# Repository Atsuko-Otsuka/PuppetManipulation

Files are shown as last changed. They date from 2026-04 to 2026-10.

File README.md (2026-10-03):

# VRぬいぐるみアバター操作システム

ぬいぐるみの身体動作を用いてVR空間のアバターを操作するシステムです。ユーザーがぬいぐるみを「触る」「動かす」ことで、アバターに直感的な身体表現を与えます。全身ボディトラッキングのような装着負担を抑えながら、手軽に自然な操作を実現することを目指しています。

## 概要

### 背景

VR空間におけるアバター操作は普及が進む一方で、従来の手法には次のような課題がありました。

- 全身ボディトラッキングでは、ユーザー自身の身体動作をそのまま反映できる一方で、装着や長時間の運用に伴う身体的負担が大きい
- ボタン式コントローラでは、比較的手軽に操作できる一方で、入力とアバターの動作が一致せず、身体としての直感的な操作が難しい

### 提案

本システムでは、これらの課題を同時に解決するために「ぬいぐるみ」をインターフェースとして採用しました。

ぬいぐるみを用いることで、ユーザーは自然な身体動作をそのままアバター操作に転写できます。これにより、最小限の身体負荷で思い通りの動作を実現しつつ、ユーザーの心理的ハードルを下げることができます。特に、ぬいぐるみを媒介にすることで、キャラクターになりきって大胆で愛らしい動作を自然に引き出すことが可能になります。

## システム構成
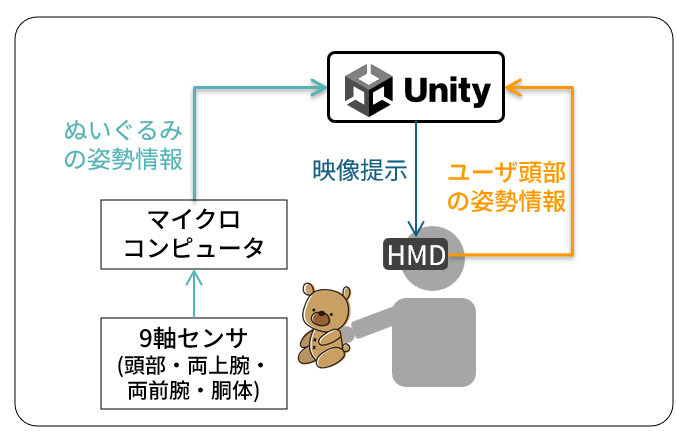
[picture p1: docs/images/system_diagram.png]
フロー図


### 主要な構成

- 9軸センサ（頭部、両上腕、両前腕、胴体）
- マルチプレクサ（I2C通信）
- XIAO ESP32-C6 マイコン
- Unity ベースのVRアプリケーション
- Meta Quest 3 による視覚提示
- 3Dプリントした筐体とぬいぐるみ内部への搭載

### 通信構成

```
9軸センサ × 7
   ↓ I2C
マルチプレクサ
   ↓ I2C
XIAO ESP32-C6 (マイコン)
   ↓ UDP
PC (Unity)
   ↓
Meta Quest 3 HMD
```

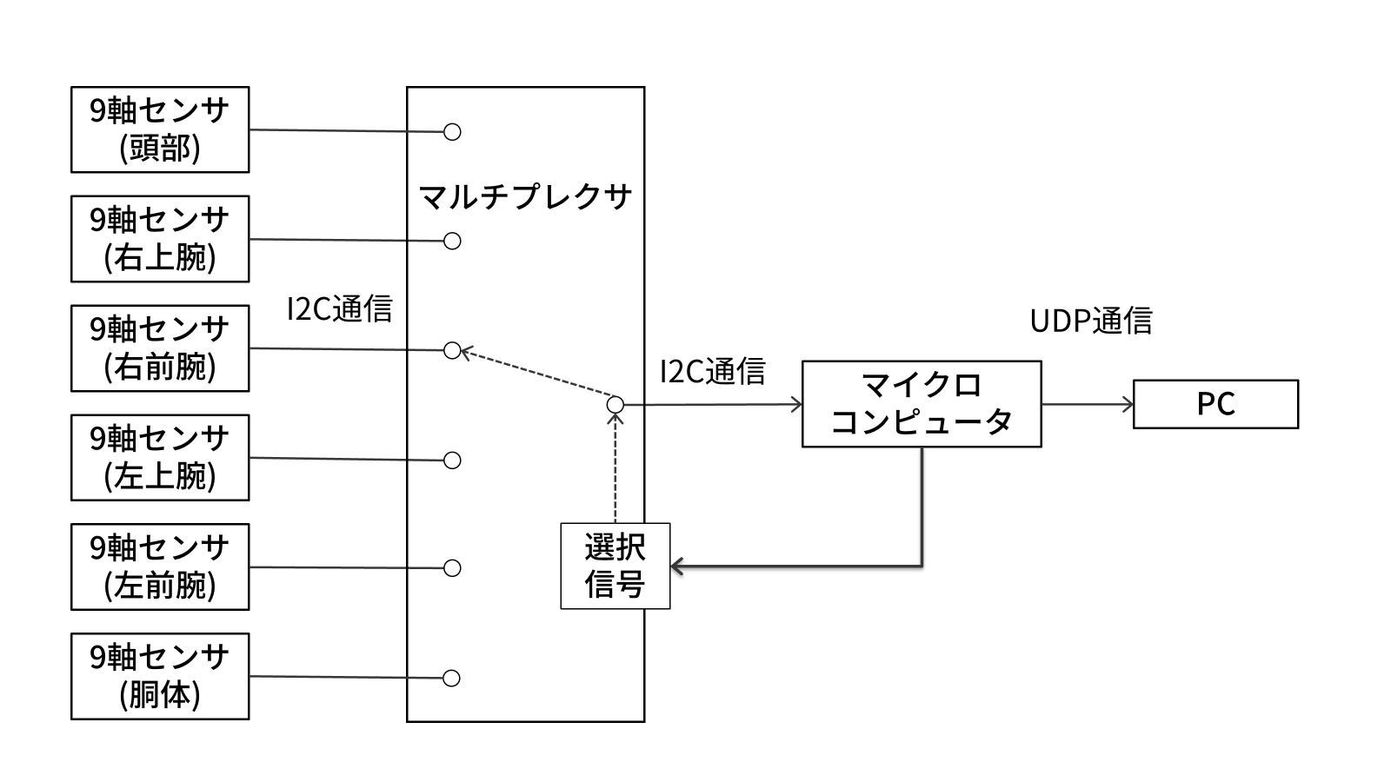
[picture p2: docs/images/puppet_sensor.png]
ハードウェア構成


- センサ群は I2C で集約されます
- マイコンがセンサデータを PC に送信します
- PC 上の Unity でアバターの姿勢と動作を更新します
- HMD によってユーザーは VR 空間でアバターを視覚的に確認します

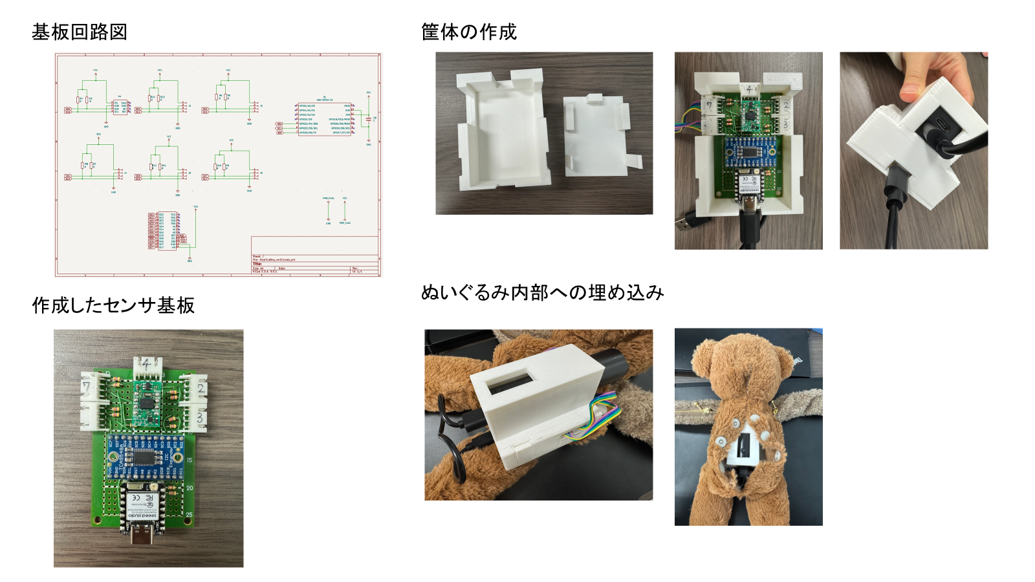
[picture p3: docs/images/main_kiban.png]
メイン基板

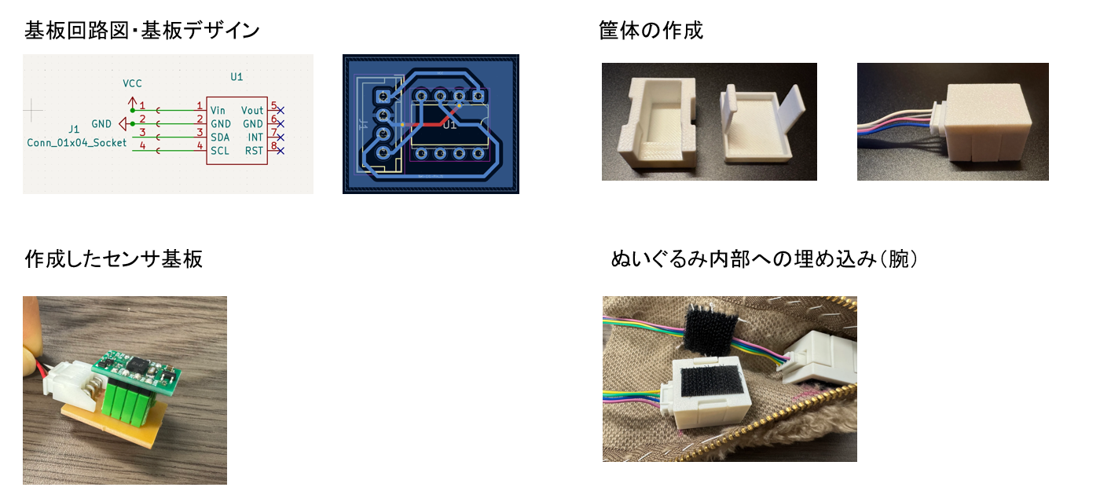
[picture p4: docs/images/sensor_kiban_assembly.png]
センサ基板


## 使用技術

- Unity（VRアプリケーション開発、アバター制御）
- Arduino IDE / XIAO ESP32-C6（センサデータの取得、PCへのデータ送信）
- KiCad（基板作成）
- Meta Quest 3（ユーザーへの視覚提示）
- Fusion360 / Bamboo Studio（筐体のモデリング、3Dプリンター印刷）

## 通信方式

本システムでは、センサデータを PC へ送信するために UDP 通信を採用しています。

- 通信方式: UDP
- 通信対象: マイコンボード → PC
- 役割: 9軸センサの姿勢情報をリアルタイムに送信し、Unityでアバター制御に反映
- 特徴: 低遅延・ワイヤレス・リアルタイム操作に適している

センサデータはI2Cでマルチプレクサ経由で収集され、ESP32-C6側でパケット化されたのち、Unityへ送信されます。

## ハードウェア詳細

### センサ配置

本システムでは7箇所に9軸センサを配置しています。

- 頭部
- 右上腕
- 右前腕
- 左上腕
- 左前腕
- 胴体
- 追加の計測部位（実装に応じて可変）

### 基板と筐体

- KiCad で設計したセンサ基板を使用
- マルチプレクサにより複数のセンサを一括制御
- 3Dプリントで筐体を作成し、ぬいぐるみの内部へ埋め込み
- ぬいぐるみの内部にセンサユニットを埋め込み、見た目と操作性を両立

### 3Dプリントと製作例

- 基板回路図と基板デザインを作成
- 筐体をプリントして内部に組み込み
- ぬいぐるみ内部へセンサー基板と配線を納めて完成

## システムの流れ

1. ぬいぐるみの各部位で姿勢が変化する
2. 9軸センサがその変化を計測する
3. マルチプレクサを介してマイコンへ送信される
4. XIAO ESP32-C6 が UDP で Unity 側へデータ送信する
5. Unity が受信した姿勢情報をアバターの各部位へ適用する
6. HMD を通じてユーザーは VR 空間で操作結果を確認する

## 実装上のポイント

- センサの取り付け位置は、アバターの自然な動きと操作性を両立するように設計
- ぬいぐるみ内部への埋め込みにより、見た目の違和感を抑制
- アバターの動きは、姿勢角度をそのまま各ボーンへ反映するのではなく、必要に応じて補正や平滑化を行う
- UDP の低遅延性を活かして、VR環境における直感的な操作を優先

## 実装ファイル

このリポジトリには、Unity側の操作スクリプトやシリアル/UDP関連の実装が含まれています。

- Unity アプリケーション: `PuppetManipulation_Software/`
- ハードウェア(基板、Arduino IDE、3Dプリンタデータなど): `PuppetManipulation_Hardware/`
- センサ制御と通信: `Assets/` 配下のスクリプト群
- キャラクター制御: `Assets/Scripts/Puppet/` など

## セットアップ

### 必要な環境

- Unity
- Meta Quest 3
- XIAO ESP32-C6
- Arduino IDE
- KiCad（基板改造時）
- 3Dプリンタ（筐体作成時）

### 基本的な手順

1. このリポジトリをクローンする
2. Unity プロジェクトを開く
3. マイコンにセンサ制御プログラムを書き込む
4. ぬいぐるみにセンサユニットを取り付ける
5. Unity 実行時に UDP 接続を確認する
6. VR 空間でアバターが動くことを確認する

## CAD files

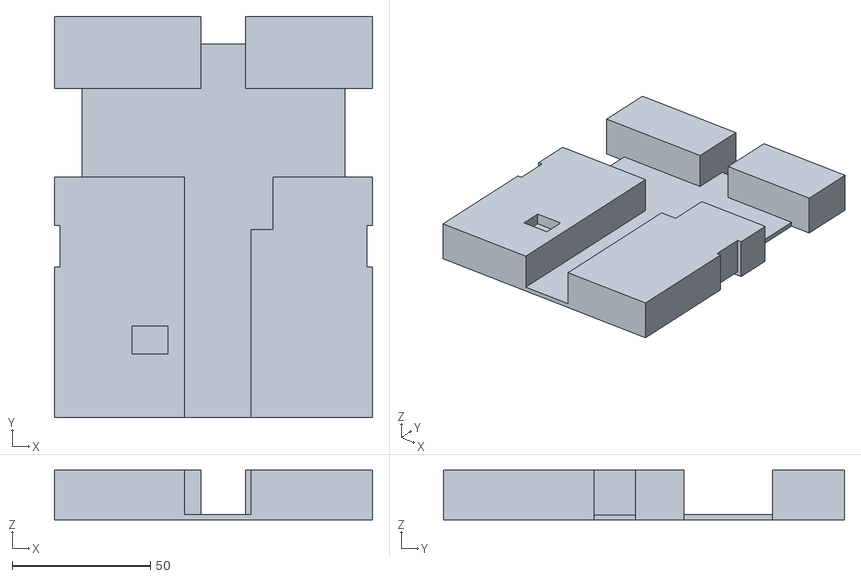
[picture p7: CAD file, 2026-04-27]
PuppetManipulation_Hardware/3DPrinter/mainPico_box.stl
115.0 x 145.0 x 18.0

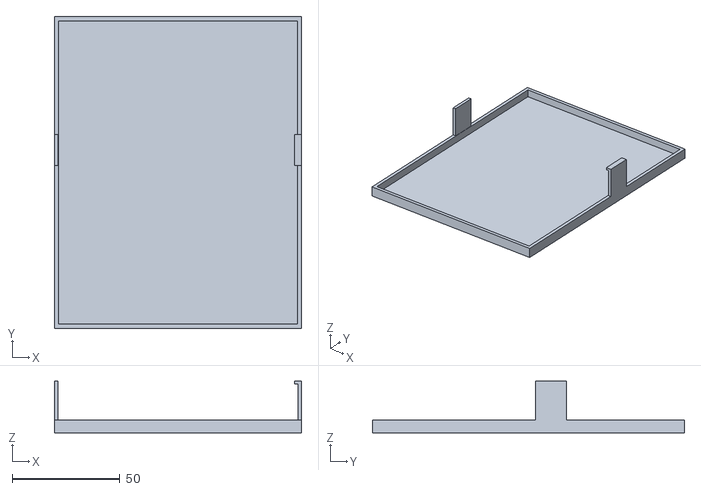
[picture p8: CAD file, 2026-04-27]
PuppetManipulation_Hardware/3DPrinter/mainPico_cover.stl
115.0 x 145.0 x 24.0

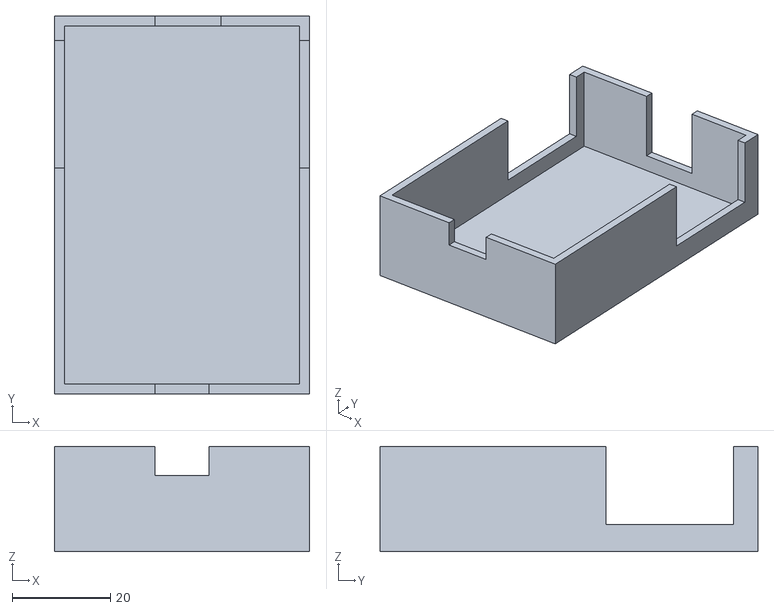
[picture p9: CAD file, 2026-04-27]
PuppetManipulation_Hardware/3DPrinter/XIAO+Multi+9jiku6_Box.stl
52.0 x 77.0 x 21.5

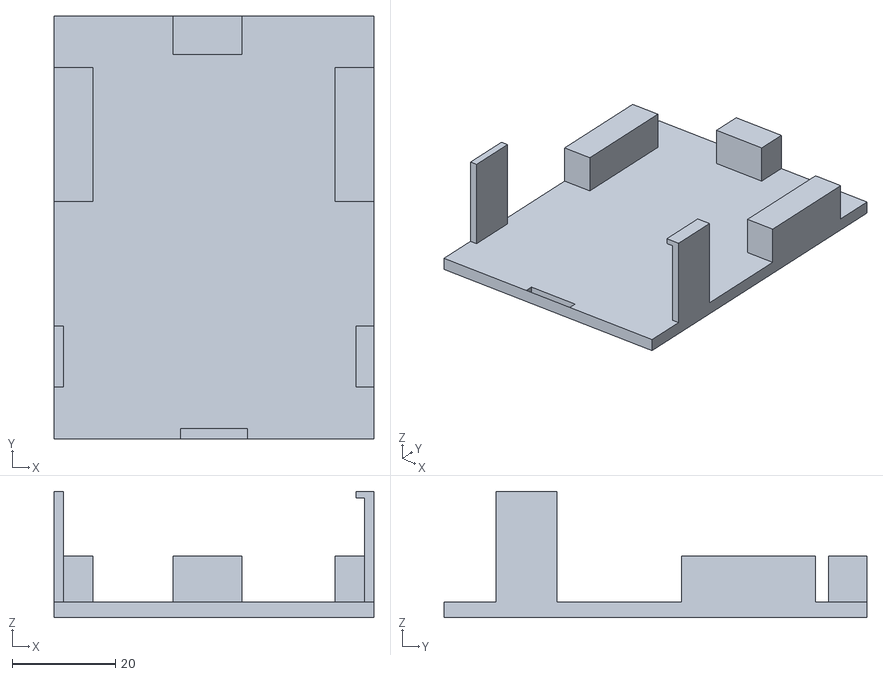
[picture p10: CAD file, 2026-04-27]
PuppetManipulation_Hardware/3DPrinter/XIAO+Multi+9jiku6_Cover_ver2.2.stl
62.0 x 82.0 x 24.5

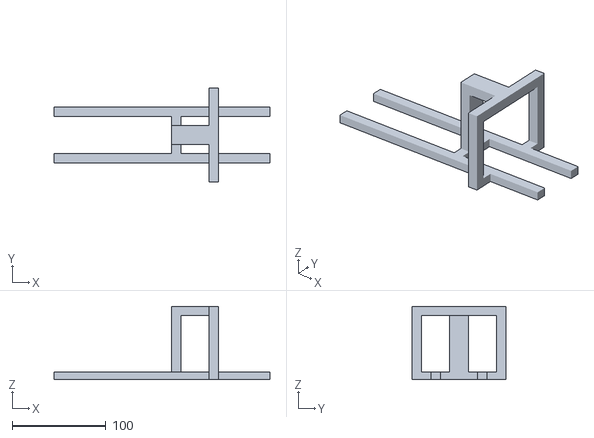
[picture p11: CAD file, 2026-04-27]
PuppetManipulation_Hardware/3DPrinter/PuppetStandStick_ver2.stl
230.0 x 100.0 x 78.1

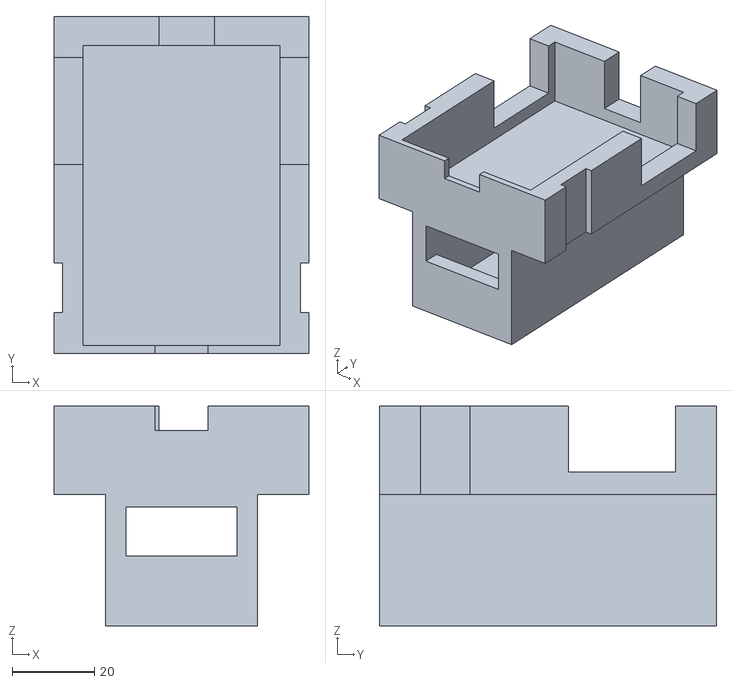
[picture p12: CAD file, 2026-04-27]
PuppetManipulation_Hardware/3DPrinter/XIAO+Multi+9jiku6_Battery_Box.stl
62.0 x 82.0 x 53.5

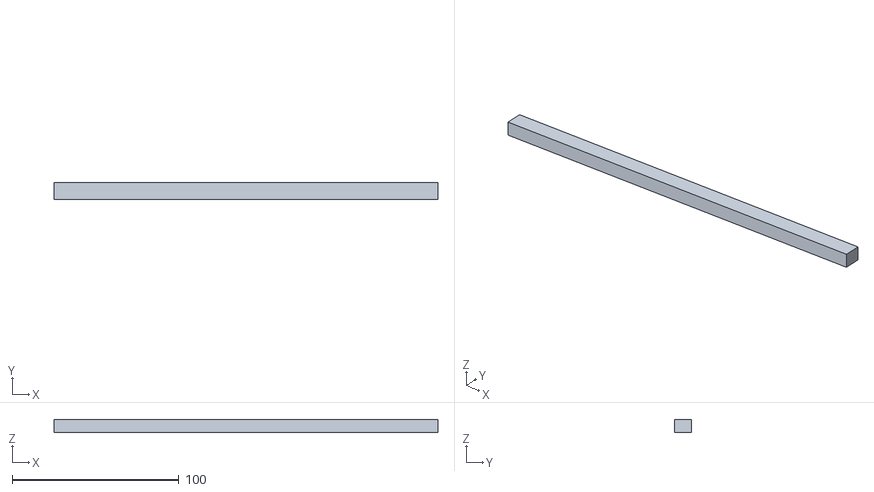
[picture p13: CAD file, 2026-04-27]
PuppetManipulation_Hardware/3DPrinter/PuppetStandStick.stl
230.0 x 10.1 x 8.05

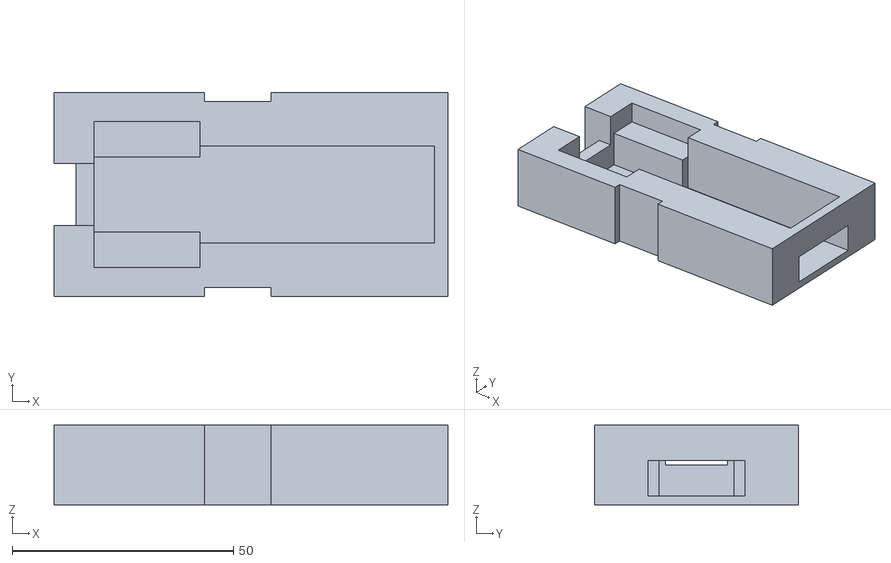
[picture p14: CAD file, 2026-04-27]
PuppetManipulation_Hardware/3DPrinter/RasPi_BNO2_Box.stl
89.0 x 46.0 x 18.0

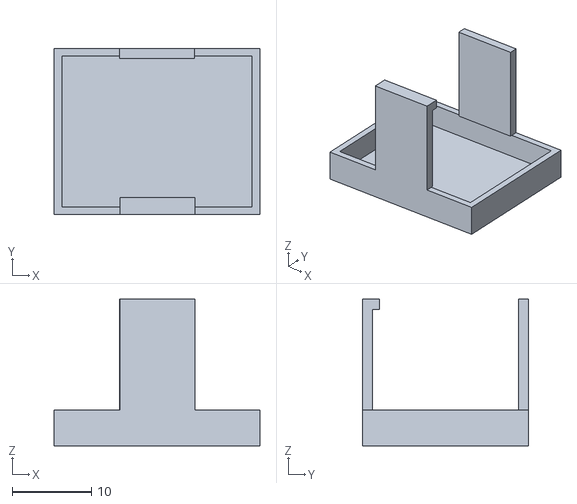
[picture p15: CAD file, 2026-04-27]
PuppetManipulation_Hardware/3DPrinter/BNO055_Cover.stl
26.0 x 21.0 x 18.5

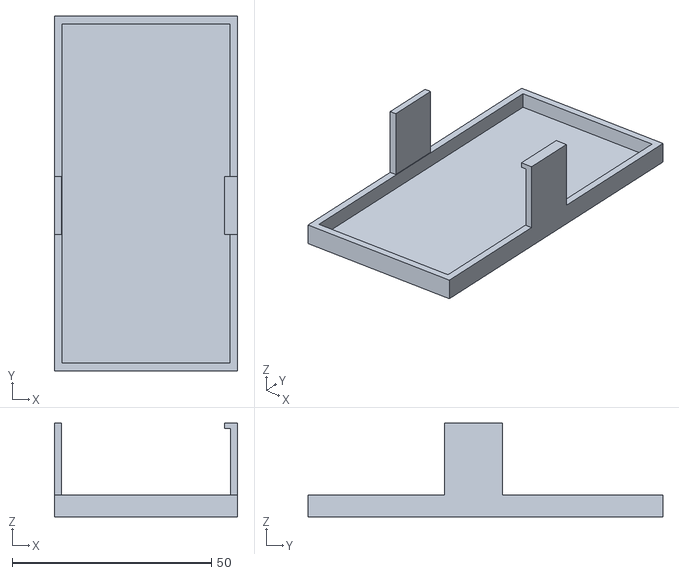
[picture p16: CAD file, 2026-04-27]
PuppetManipulation_Hardware/3DPrinter/RasPi_BNO2_I2C_Cover.stl
46.0 x 89.0 x 23.5

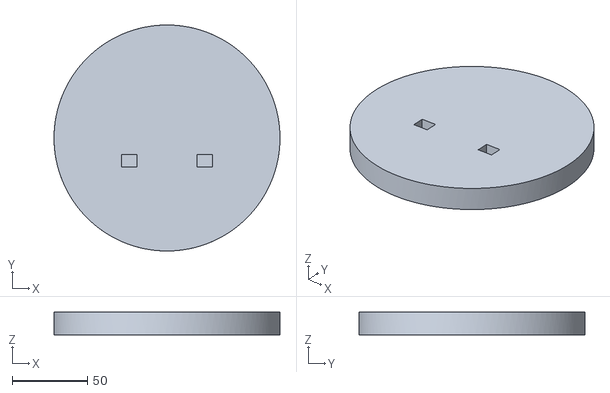
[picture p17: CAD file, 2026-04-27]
PuppetManipulation_Hardware/3DPrinter/PuppetStandBoard.stl
150.0 x 150.0 x 15.0

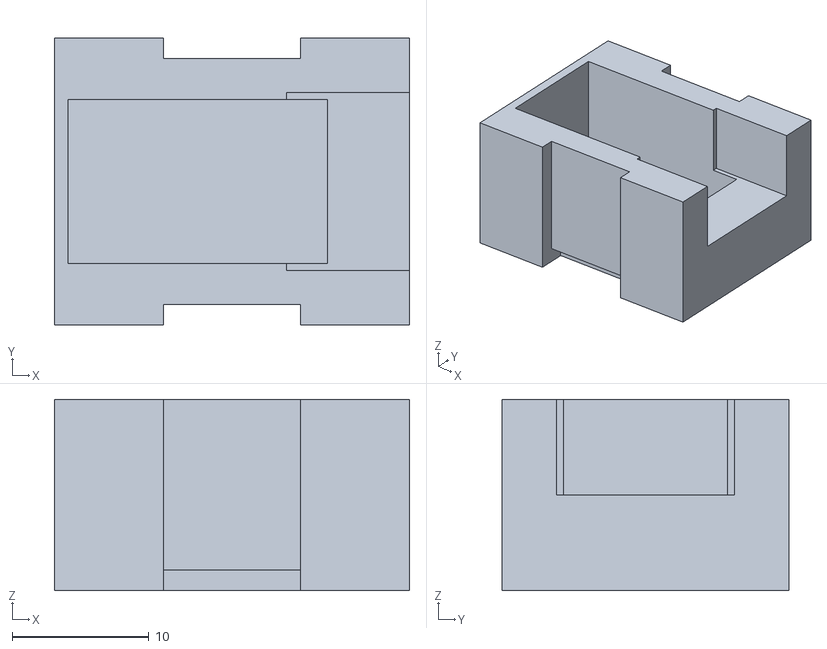
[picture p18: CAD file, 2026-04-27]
PuppetManipulation_Hardware/3DPrinter/BNO055_Box.stl
26.0 x 21.0 x 14.0

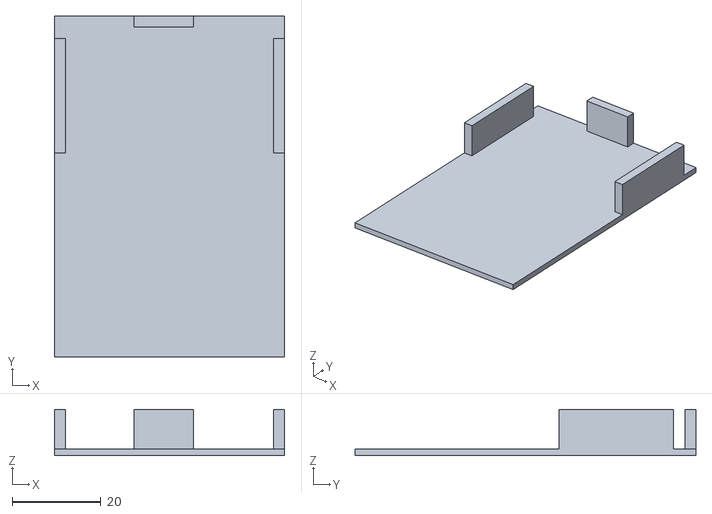
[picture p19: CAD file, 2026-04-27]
PuppetManipulation_Hardware/3DPrinter/XIAO+Multi+9jiku6_Cover.stl
52.0 x 77.0 x 10.5

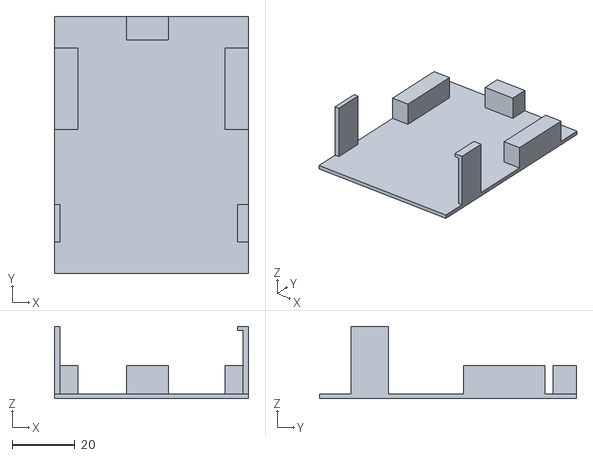
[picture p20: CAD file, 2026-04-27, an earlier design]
PuppetManipulation_Hardware/3DPrinter/XIAO+Multi+9jiku6_Cover_ver2.stl
62.0 x 82.0 x 23.0

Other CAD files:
PuppetManipulation_Hardware/3DPrinter/XIAO+Multi+9jiku6_Battery_Box_ver3.stl
PuppetManipulation_Hardware/3DPrinter/XIAO+Multi+9jiku6_Battery_Box_ver2.stl

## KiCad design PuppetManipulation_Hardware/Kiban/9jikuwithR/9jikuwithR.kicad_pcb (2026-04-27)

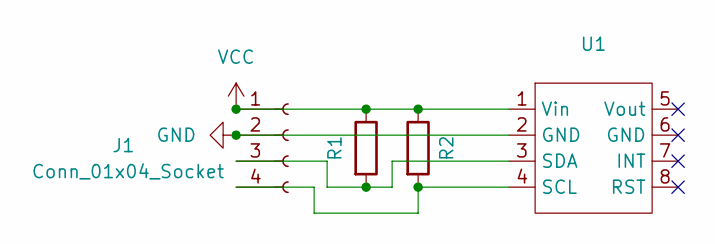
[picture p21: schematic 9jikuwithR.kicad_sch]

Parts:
J1: Conn_01x04_Socket; JST_XH_B4B-XH-A_1x04_P2.50mm_Vertical
R1, R2: R; R_Axial_DIN0207_L6.3mm_D2.5mm_P7.62mm_Horizontal
U1: DIP-8_W7.62mm

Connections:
GND: J1.2, U1.2 (GND)
unnamed: J1.3, R1.2, U1.3 (SDA)
unnamed: J1.4, R2.2, U1.4 (SCL)
VCC: J1.1, R1.1, R2.1, U1.1 (Vin)

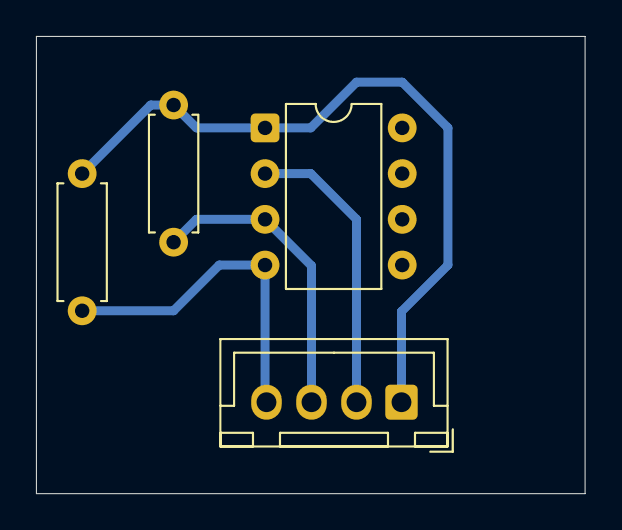
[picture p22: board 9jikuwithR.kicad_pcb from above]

Board: 2 copper layers, 30.5 x 25.4 mm, 4 parts (0 on the bottom side), 4 nets.

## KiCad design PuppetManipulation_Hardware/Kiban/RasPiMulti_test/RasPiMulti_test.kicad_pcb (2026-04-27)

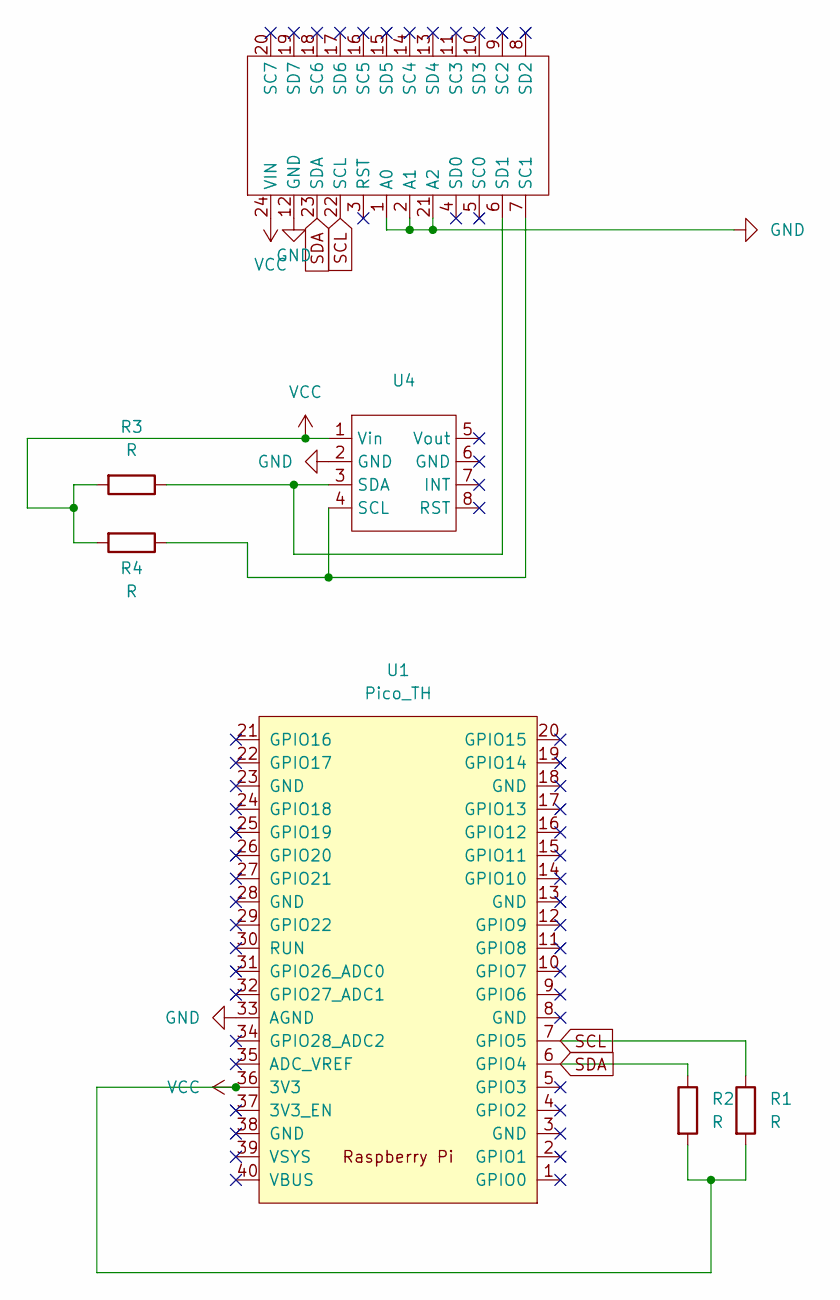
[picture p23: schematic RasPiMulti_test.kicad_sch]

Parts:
R1, R2, R3, R4: R; R_Axial_DIN0204_L3.6mm_D1.6mm_P7.62mm_Horizontal
U1: Pico_TH; RPi_Pico_TH
U2: TCA9548A
U4: DIP-8_W7.62mm

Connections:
GND: U1.33 (AGND), U2.1 (A0), U2.2 (A1), U2.12 (GND), U2.21 (A2), U4.2 (GND)
unnamed: R4.1, U2.7 (SC1), U4.4 (SCL)
unnamed: R3.1, U2.6 (SD1), U4.3 (SDA)
SCL: R1.1, U1.7 (GPIO5), U2.22 (SCL)
SDA: R2.1, U1.6 (GPIO4), U2.23 (SDA)
VCC: R1.2, R2.2, R3.2, R4.2, U1.36 (3V3), U2.24 (VIN), U4.1 (Vin)

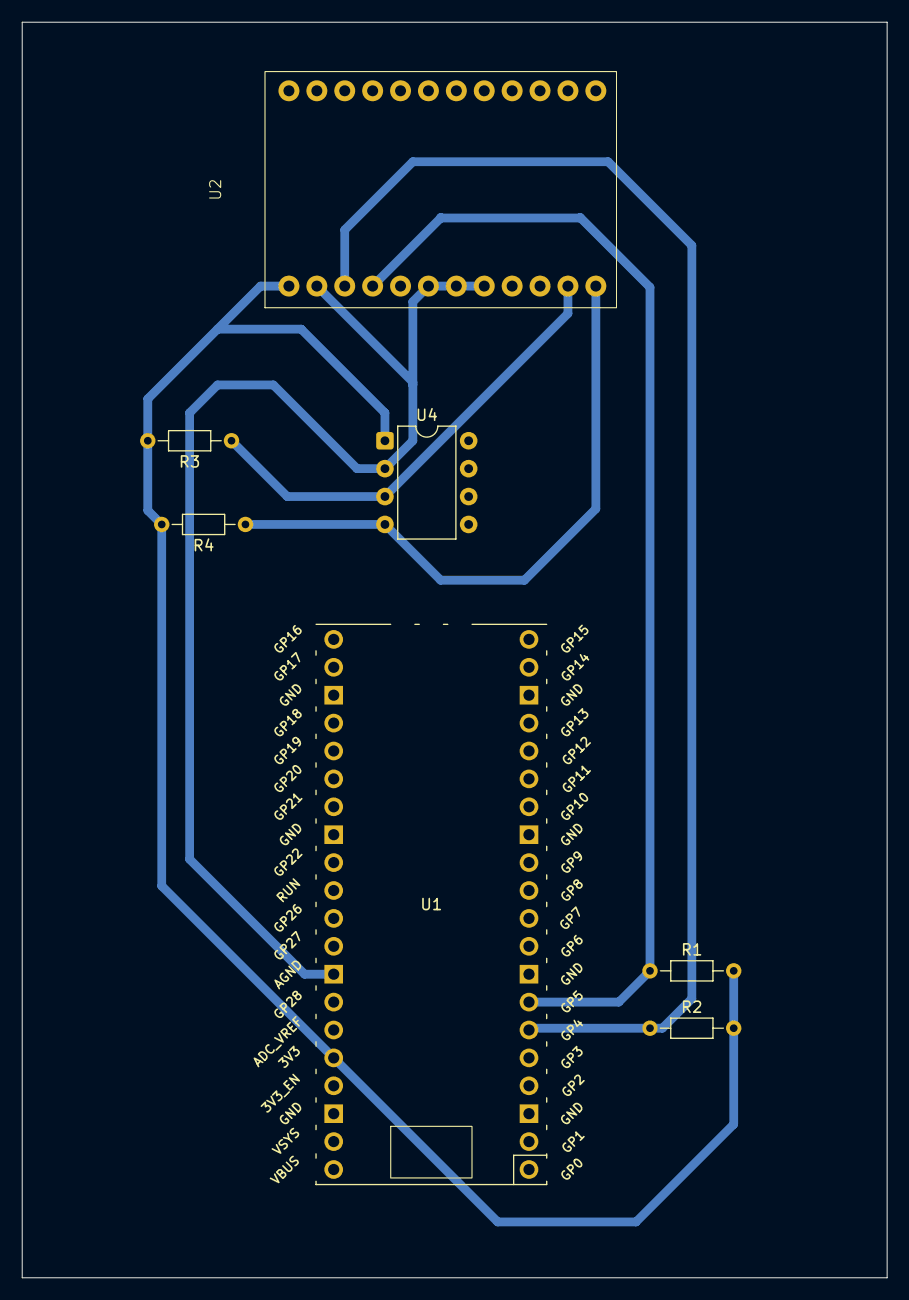
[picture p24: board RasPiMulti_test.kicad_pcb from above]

Board: 2 copper layers, 78.7 x 114.3 mm, 7 parts (0 on the bottom side), 6 nets.

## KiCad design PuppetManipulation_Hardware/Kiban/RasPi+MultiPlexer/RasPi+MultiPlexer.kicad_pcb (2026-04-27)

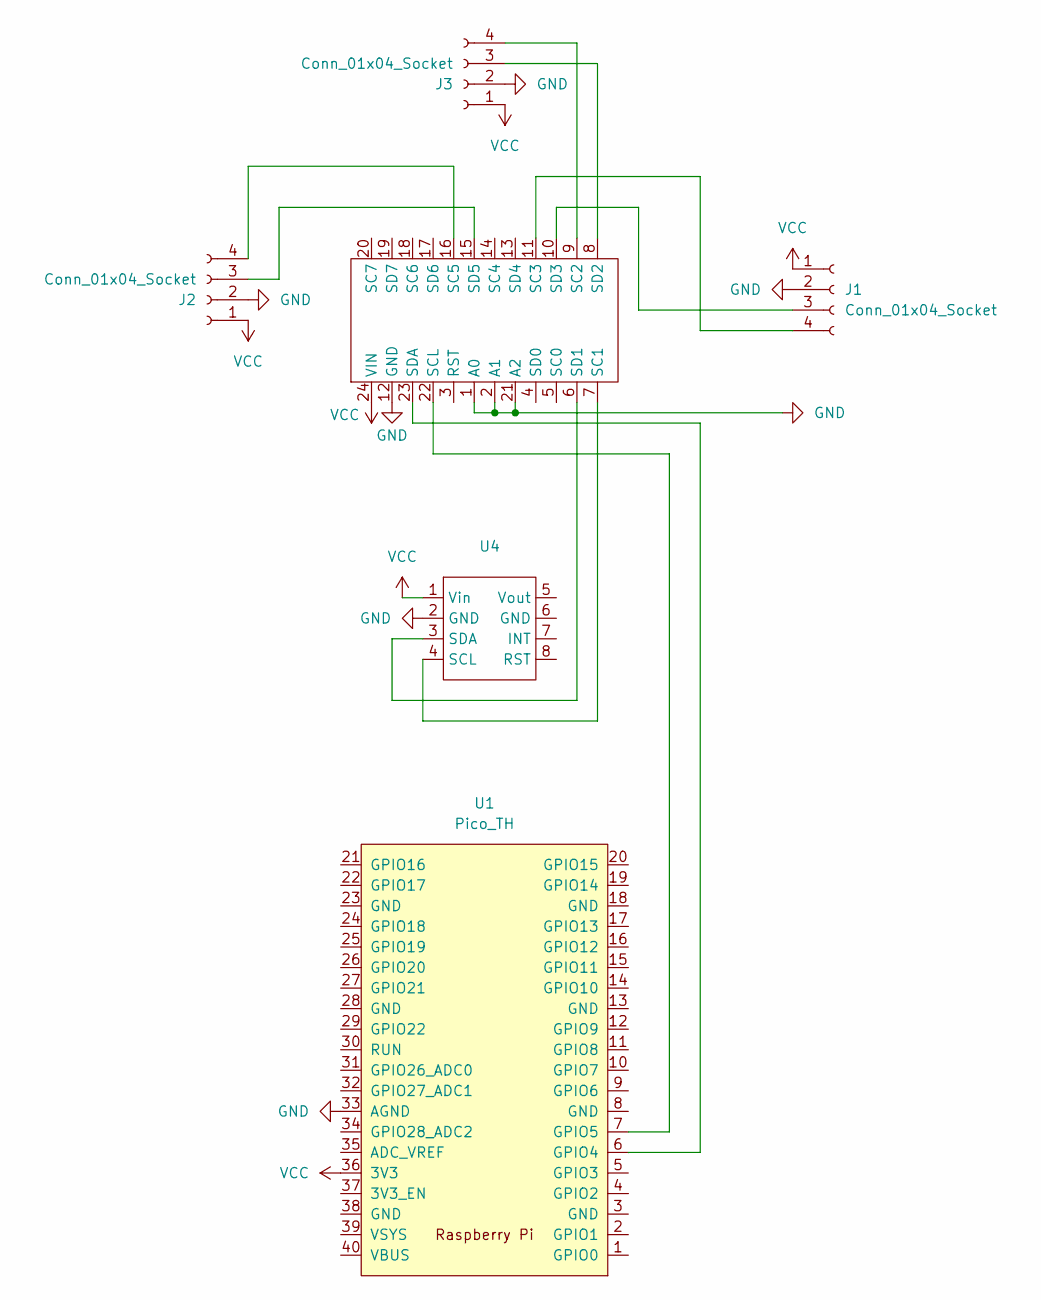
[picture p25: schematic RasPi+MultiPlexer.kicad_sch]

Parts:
J1, J2, J3: Conn_01x04_Socket; JST_XH_S4B-XH-A_1x04_P2.50mm_Horizontal
U1: Pico_TH; RPi_Pico_TH
U2: TCA9548A
U4: DIP-8_W7.62mm

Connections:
GND: J1.2, J2.2, J3.2, U1.33 (AGND), U2.1 (A0), U2.2 (A1), U2.12 (GND), U2.21 (A2), U4.2 (GND)
unnamed: J1.3, U2.10 (SD3)
unnamed: J1.4, U2.11 (SC3)
unnamed: J2.3, U2.15 (SD5)
unnamed: J2.4, U2.16 (SC5)
unnamed: J3.3, U2.8 (SD2)
unnamed: J3.4, U2.9 (SC2)
unnamed: U1.6 (GPIO4), U2.23 (SDA)
unnamed: U1.7 (GPIO5), U2.22 (SCL)
unnamed: U2.7 (SC1), U4.4 (SCL)
unnamed: U2.6 (SD1), U4.3 (SDA)
VCC: J1.1, J2.1, J3.1, U1.36 (3V3), U2.24 (VIN), U4.1 (Vin)

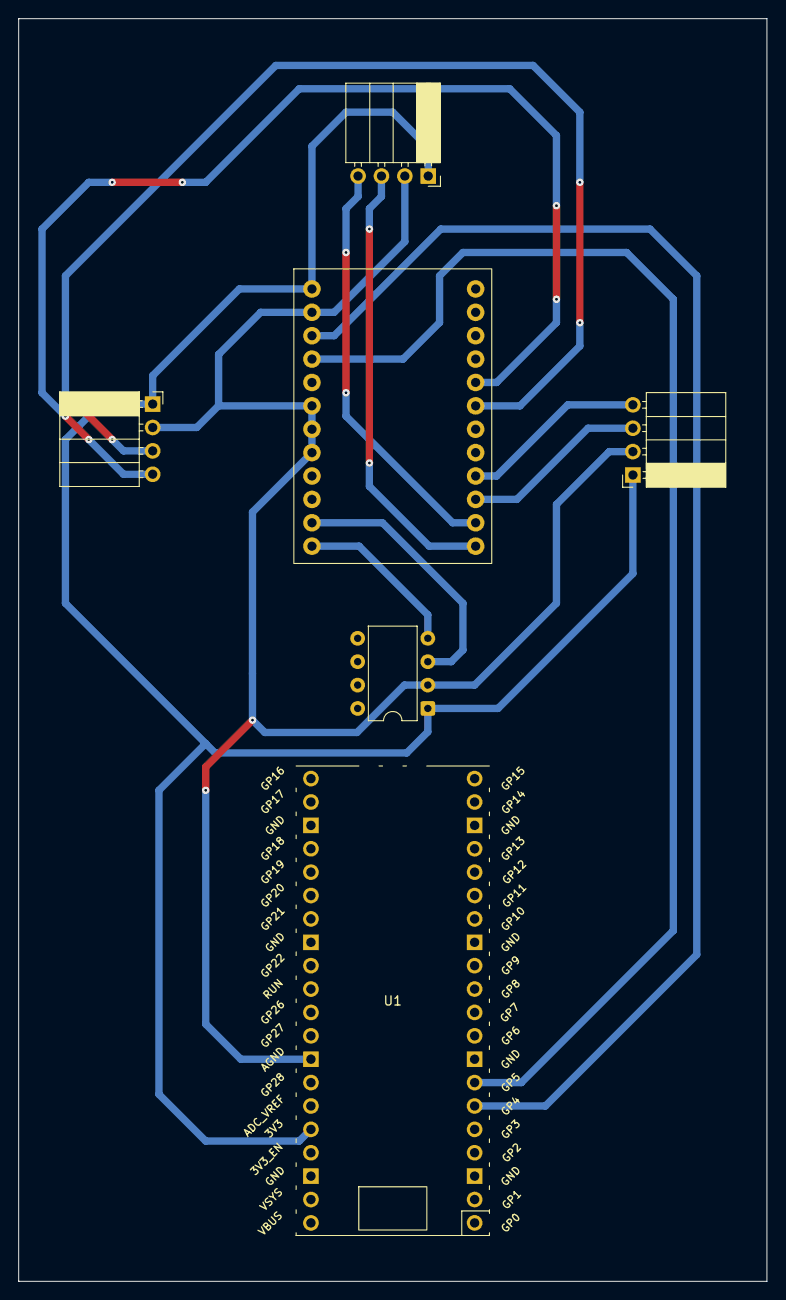
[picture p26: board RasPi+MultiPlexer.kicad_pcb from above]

Board: 2 copper layers, 81.3 x 137.2 mm, 6 parts (0 on the bottom side), 12 nets.

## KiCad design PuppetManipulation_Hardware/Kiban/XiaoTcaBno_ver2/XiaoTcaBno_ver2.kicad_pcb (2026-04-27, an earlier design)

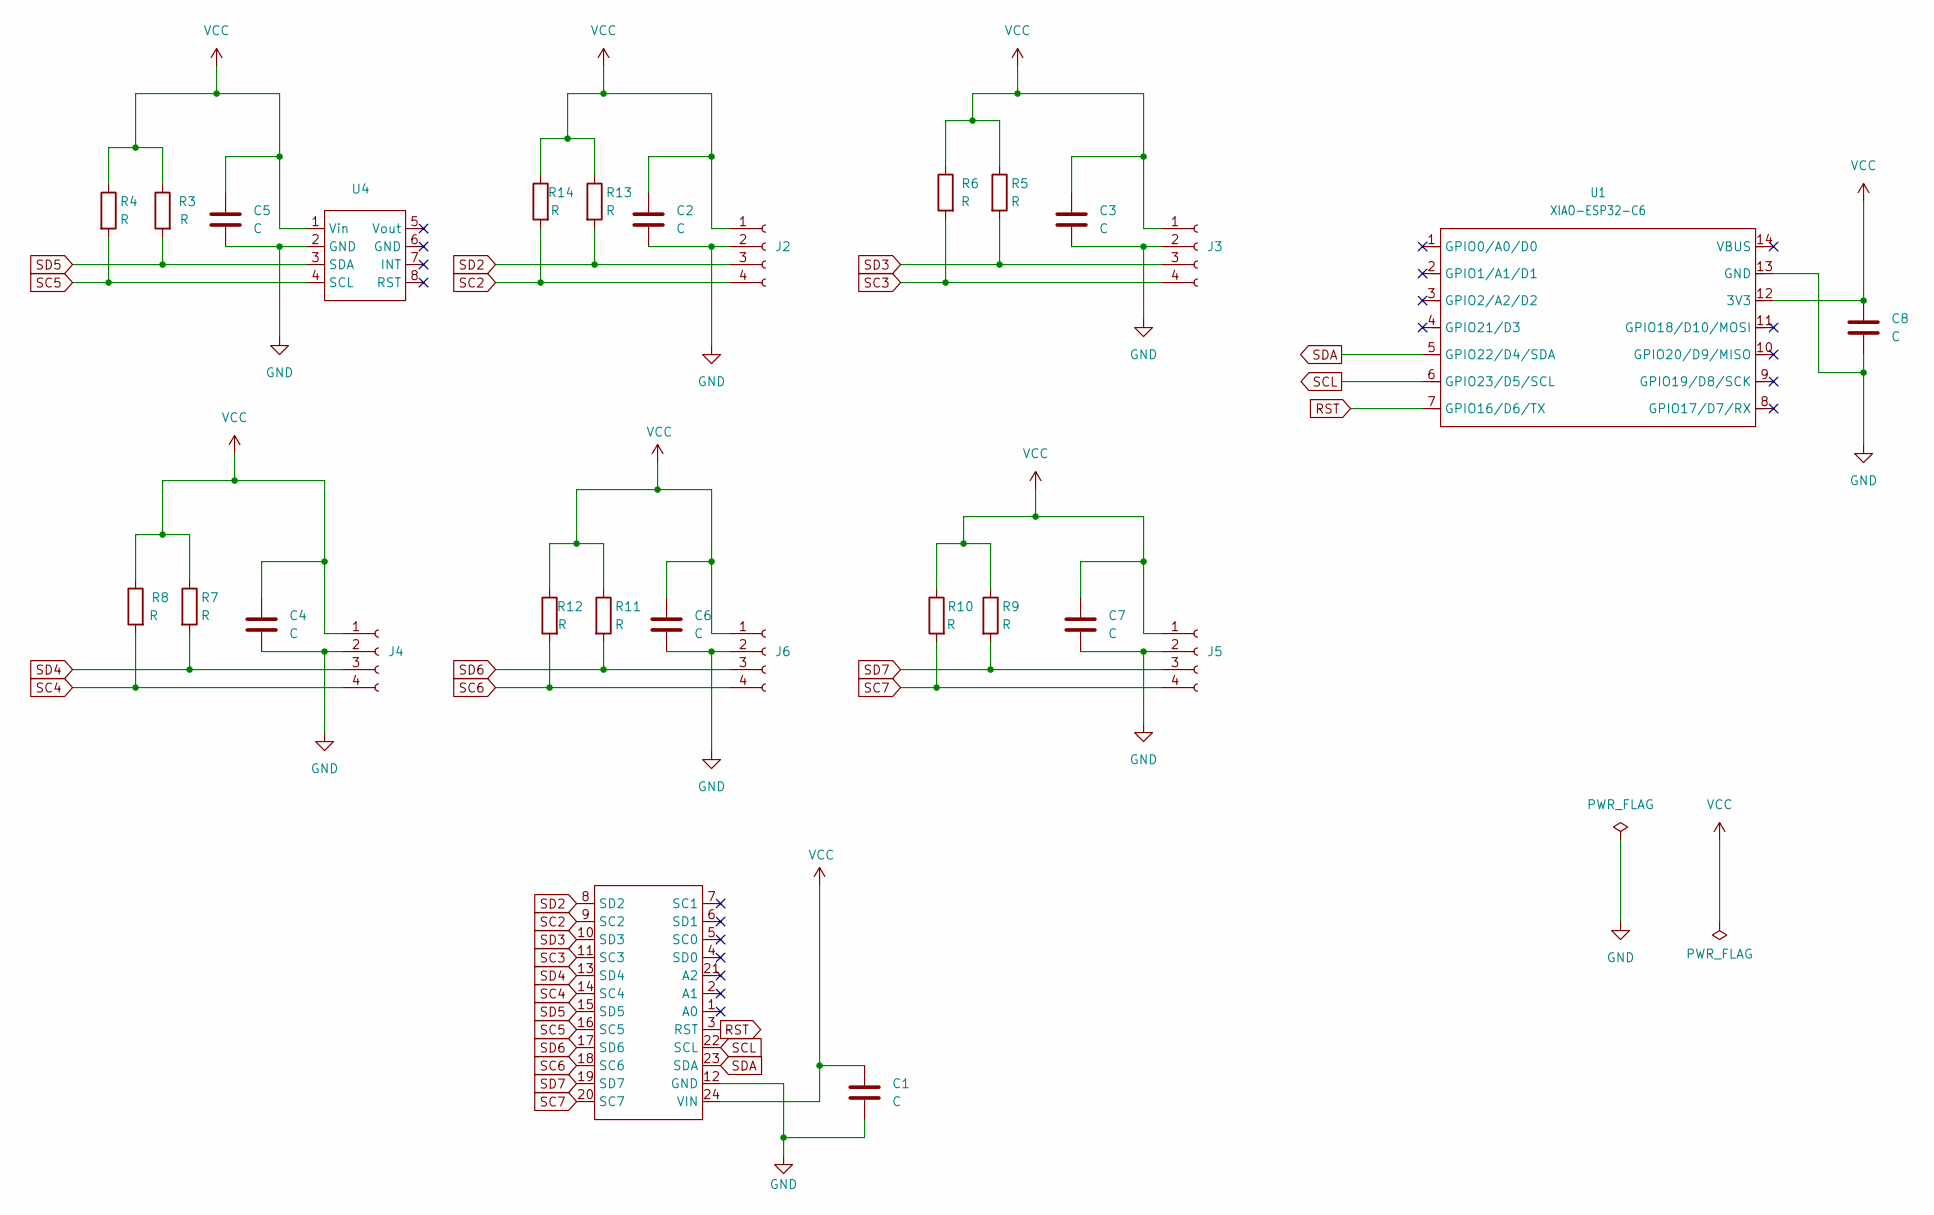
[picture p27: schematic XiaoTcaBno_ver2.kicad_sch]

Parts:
C1, C2, C3, C4, C5, C6, C7: C; C_Disc_D3.0mm_W1.6mm_P2.50mm
C8: C; CP_Radial_D6.3mm_P2.50mm
J2, J3, J4, J5, J6: Conn_01x04_Socket; JST_XH_B4B-XH-A_1x04_P2.50mm_Vertical
R3, R4, R5, R6, R7, R8, R9, R10, R11, R12, R13, R14: R; R_Axial_DIN0204_L3.6mm_D1.6mm_P7.62mm_Horizontal
U1: XIAO-ESP32-C6; XIAO-ESP32-C6-DIP
U2: TCA9548A
U4: DIP-8_W7.62mm

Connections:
GND: C1.2, C2.2, C3.2, C4.2, C5.2, C6.2, C7.2, C8.2, J2.2, J3.2, J4.2, J5.2, J6.2, U1.13 (GND), U2.12 (GND), U4.2 (GND)
RST: U1.7 (GPIO16/D6/TX), U2.3 (RST)
SC2: J2.4, R14.2, U2.9 (SC2)
SC3: J3.4, R6.2, U2.11 (SC3)
SC4: J4.4, R8.2, U2.14 (SC4)
SC5: R4.2, U2.16 (SC5), U4.4 (SCL)
SC6: J6.4, R12.2, U2.18 (SC6)
SC7: J5.4, R10.2, U2.20 (SC7)
SCL: U1.6 (GPIO23/D5/SCL), U2.22 (SCL)
SD2: J2.3, R13.2, U2.8 (SD2)
SD3: J3.3, R5.2, U2.10 (SD3)
SD4: J4.3, R7.2, U2.13 (SD4)
SD5: R3.2, U2.15 (SD5), U4.3 (SDA)
SD6: J6.3, R11.2, U2.17 (SD6)
SD7: J5.3, R9.2, U2.19 (SD7)
SDA: U1.5 (GPIO22/D4/SDA), U2.23 (SDA)
VCC: C1.1, C2.1, C3.1, C4.1, C5.1, C6.1, C7.1, C8.1, J2.1, J3.1, J4.1, J5.1, J6.1, R3.1, R4.1, R5.1, R6.1, R7.1, R8.1, R9.1, R10.1, R11.1, R12.1, R13.1, R14.1, U1.12 (3V3), U2.24 (VIN), U4.1 (Vin)

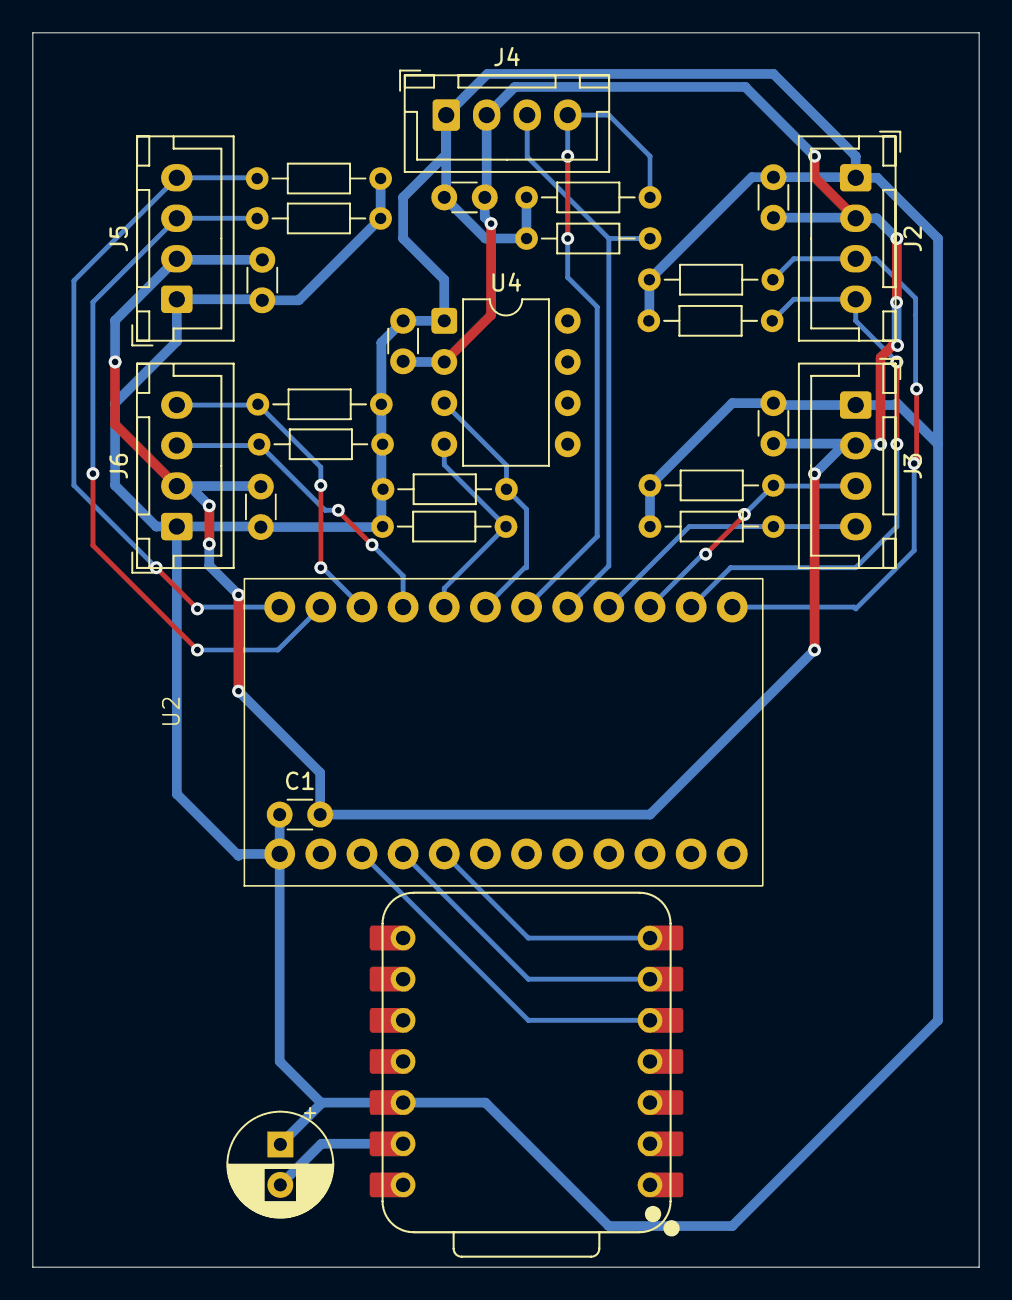
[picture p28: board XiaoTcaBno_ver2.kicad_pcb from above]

Board: 2 copper layers, 58.4 x 76.2 mm, 28 parts (0 on the bottom side), 17 nets.

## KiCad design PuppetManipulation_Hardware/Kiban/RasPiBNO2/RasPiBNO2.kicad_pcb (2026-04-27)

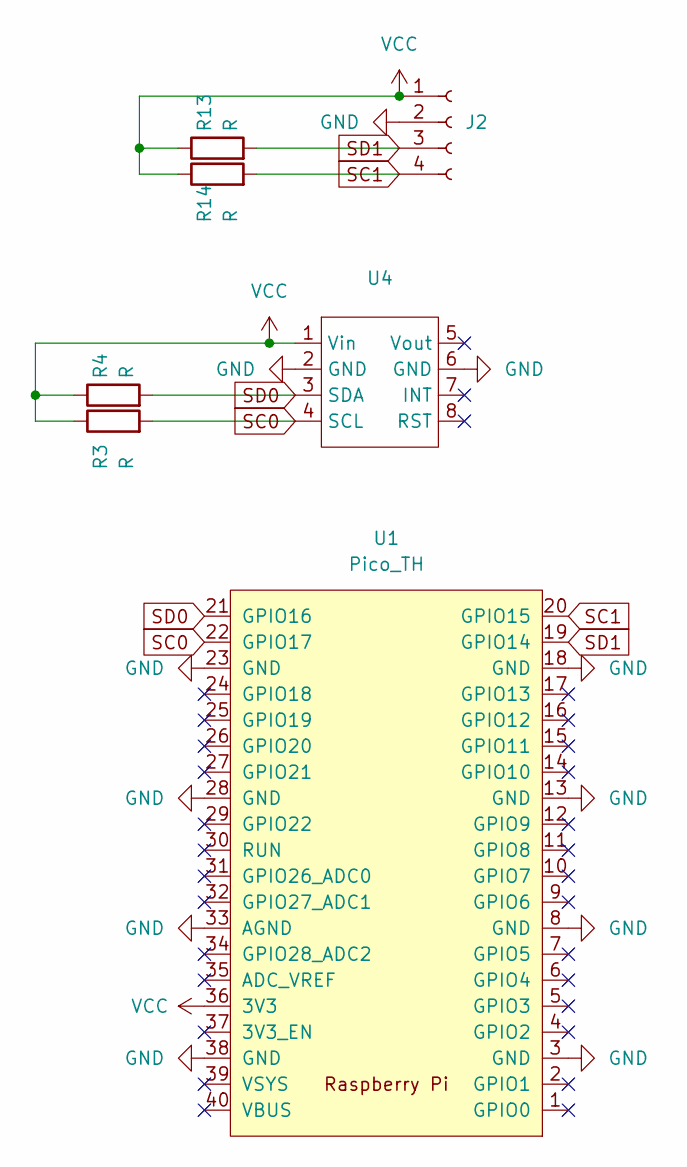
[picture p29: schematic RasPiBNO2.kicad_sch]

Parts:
J2: Conn_01x04_Socket; JST_XH_B4B-XH-A_1x04_P2.50mm_Vertical
R3, R4, R13, R14: R; R_Axial_DIN0207_L6.3mm_D2.5mm_P10.16mm_Horizontal
U1: Pico_TH; RPi_Pico_TH
U4: DIP-8_W7.62mm

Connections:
GND: J2.2, U1.3 (GND), U1.8 (GND), U1.13 (GND), U1.18 (GND), U1.23 (GND), U1.28 (GND), U1.33 (AGND), U1.38 (GND), U4.2 (GND), U4.6 (GND)
SC0: R3.2, U1.22 (GPIO17), U4.4 (SCL)
SC1: J2.4, R14.2, U1.20 (GPIO15)
SD0: R4.2, U1.21 (GPIO16), U4.3 (SDA)
SD1: J2.3, R13.2, U1.19 (GPIO14)
VCC: J2.1, R3.1, R4.1, R13.1, R14.1, U1.36 (3V3), U4.1 (Vin)

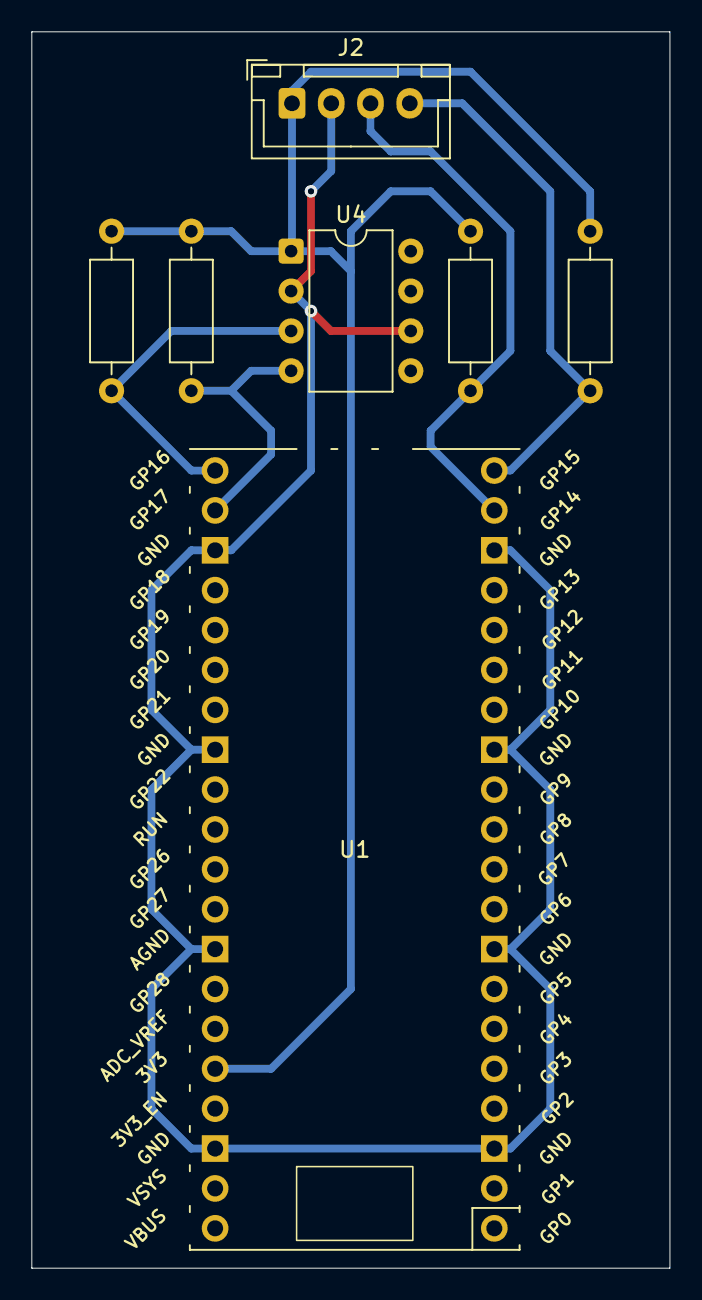
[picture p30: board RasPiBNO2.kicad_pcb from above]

Board: 2 copper layers, 40.6 x 78.7 mm, 7 parts (0 on the bottom side), 6 nets.

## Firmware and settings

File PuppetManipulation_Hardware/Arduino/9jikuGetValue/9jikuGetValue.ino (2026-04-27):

// #include <Wire.h>
// #include <Adafruit_Sensor.h>
// #include <Adafruit_BNO055.h>
// #include <utility/imumaths.h>

// /*
//  * BNO055のインスタンスを作成します。
//  * I2Cアドレスはデフォルトの0x28です。
//  * もしADRジャンパをはんだ付けしている場合は 0x29 に変更してください。
//  */
// Adafruit_BNO055 bno = Adafruit_BNO055(-1, 0x28);

// void setup(void) {
//   Serial.begin(115200);
//   Serial.println("BNO055 All Sensor Data Test");
//   Serial.println("--------------------------------");
  
//   // Pico WのカスタムI2Cピンを設定
//   Wire.setSDA(20);
//   Wire.setSCL(21);

//   // BNO055センサーを初期化
//   if (!bno.begin()) {
//     Serial.print("BNO055が検出できませんでした。配線かI2Cアドレスを確認してください。");
//     while (1);
//   }
  
//   delay(1000);
// }

// void loop(void) {
//   // 加速度センサーのベクトルデータを取得 (単位: m/s^2)
//   imu::Vector<3> accelerometer = bno.getVector(Adafruit_BNO055::VECTOR_ACCELEROMETER);

//   // ジャイロスコープのベクトルデータを取得 (単位: rad/s)
//   imu::Vector<3> gyroscope = bno.getVector(Adafruit_BNO055::VECTOR_GYROSCOPE);

//   // 地磁気センサー（磁力計）のベクトルデータを取得 (単位: uT - マイクロテスラ)
//   imu::Vector<3> magnetometer = bno.getVector(Adafruit_BNO055::VECTOR_MAGNETOMETER);

//   // --- 取得した値をシリアルモニタに表示 ---

//   // 加速度
//   Serial.print("Accel X: ");
//   Serial.print(accelerometer.x());
//   Serial.print("Y: ");
//   Serial.print(accelerometer.y());
//   Serial.print("Z: ");
//   Serial.print(accelerometer.z());
//   //Serial.println(" (m/s^2)");

//   // ジャイロ
//   Serial.print("Gyro X: ");
//   Serial.print(gyroscope.x());
//   Serial.print("Y: ");
//   Serial.print(gyroscope.y());
//   Serial.print("Z: ");
//   Serial.print(gyroscope.z());
//   //Serial.println(" (rad/s)");

//   // 地磁気
//   Serial.print("Mag X: ");
//   Serial.print(magnetometer.x());
//   Serial.print("Y: ");
//   Serial.print(magnetometer.y());
//   Serial.print("Z: ");
//   Serial.print(magnetometer.z());
//   //Serial.println(" (uT)");
  
//   Serial.println(""); // 見やすくするために改行
  
//   delay(500); // 0.5秒ごとにデータを更新
// }


#include <Wire.h>
#include <Adafruit_Sensor.h>
#include <Adafruit_BNO055.h>
#include <utility/imumaths.h>

/*
 * BNO055のインスタンスを作成します。
 * I2Cアドレスはデフォルトの0x28です。
 * もしADRジャンパをはんだ付けしている場合は 0x29 に変更してください。
 */
Adafruit_BNO055 bno = Adafruit_BNO055(-1, 0x28);

void setup(void) {
  Serial.begin(115200);
  Serial.println("BNO055 All Sensor Data Test");
  Serial.println("--------------------------------");
  
  // Pico WのカスタムI2Cピンを設定
  // Wire.setSDA(20);
  // Wire.setSCL(21);
  
  // XIAO ESP32C6の場合
  Wire.begin();

  // BNO055センサーを初期化
  if (!bno.begin()) {
    Serial.print("BNO055が検出できませんでした。配線かI2Cアドレスを確認してください。");
    while (1);
  }
  
  delay(1000);
}

void loop(void) {
  // 加速度センサーのベクトルデータを取得 (単位: m/s^2)
  imu::Vector<3> accelerometer = bno.getVector(Adafruit_BNO055::VECTOR_ACCELEROMETER);

  // ジャイロスコープのベクトルデータを取得 (単位: rad/s)
  imu::Vector<3> gyroscope = bno.getVector(Adafruit_BNO055::VECTOR_GYROSCOPE);

  // 地磁気センサー（磁力計）のベクトルデータを取得 (単位: uT - マイクロテスラ)
  imu::Vector<3> magnetometer = bno.getVector(Adafruit_BNO055::VECTOR_MAGNETOMETER);

  // --- 取得した値をシリアルモニタに表示 ---

  // 加速度
  Serial.print(accelerometer.x());
  Serial.print(",");
  Serial.print(accelerometer.y());
  Serial.print(",");
  Serial.print(accelerometer.z());
  Serial.print(",");
  //ジャイロ
  Serial.print(gyroscope.x());
  Serial.print(",");
  Serial.print(gyroscope.y());
  Serial.print(",");
  Serial.print(gyroscope.z());
  Serial.print(",");
  // 地磁気
  Serial.print(magnetometer.x());
  Serial.print(",");
  Serial.print(magnetometer.y());
  Serial.print(",");
  Serial.println(magnetometer.z());
  

  
  
  // Serial.println(""); // 見やすくするために改行
  
  delay(500); // 0.5秒ごとにデータを更新
}

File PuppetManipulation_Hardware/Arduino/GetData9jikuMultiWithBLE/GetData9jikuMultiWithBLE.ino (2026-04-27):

//Server Code
#include <BLEDevice.h>
#include <BLEUtils.h> // BLEのユーティリティ（UUID変換など）
#include <BLEServer.h> // BLEサーバー（データ送信側）としての機能

#include <Wire.h> // I2C通信用
#include <Adafruit_Sensor.h>
#include <Adafruit_BNO055.h>
#include <utility/imumaths.h> // クォータニオン計算用

// --- 通信の識別子（UUID）の設定 ---
#define SERVICE_UUID        "9d8c03f6-a988-4647-9474-dedaedf309e0" 
#define CHARACTERISTIC_UUID "bfbadb76-f1d7-4b84-9e66-82ac847e21fa" 

// --- マルチプレクサ設定 ---
#define TCAADDR 0x70       // TCA9548AのI2Cアドレス
#define NUM_SENSORS 8      // マルチプレクサのポート数 (最大8)

// --- BNO055 設定 ---
#define BNO055_SAMPLERATE_DELAY_MS (20) // 各センサーの読み取り間隔
// マルチプレクサのポートを切り替える関数
void tcaselect(uint8_t i) {
  if (i > 7) return;
  Wire.beginTransmission(TCAADDR);
  Wire.write(1 << i);
  Wire.endTransmission();
}
// センサーオブジェクトをポートの数だけ配列として作成
Adafruit_BNO055 bno_sensors[NUM_SENSORS];
// 各センサーが正常に初期化されたかを記録する配列
bool sensor_initialized[NUM_SENSORS];

//Adafruit_BNO055 bno = Adafruit_BNO055(55, 0x28);

// --- Bluetooth 設定 ---
BLECharacteristic *pCharacteristic;
bool deviceConnected = false;

// 接続状態を管理するコールバック
class MyServerCallbacks: public BLEServerCallbacks {
    void onConnect(BLEServer* pServer) {
      deviceConnected = true;
    };
    void onDisconnect(BLEServer* pServer) {
      deviceConnected = false;
      // 切断時にアドバタイズを再開（再接続しやすくするため）
      BLEDevice::startAdvertising();
    }
};

void setup() {
  Serial.begin(115200);
  Serial.println("Starting BLE work!");

  Wire.begin();
  Wire.setClock(400000); // I2C通信モード
  Wire.setTimeout(3000); // クロックストレッチ対策

  // すべてのポートをループして、BNO055を探し、初期化する
  for (uint8_t i = 0; i < NUM_SENSORS; i++) {
    tcaselect(i); // ポートiを選択
    Serial.print("Checking Port #");
    Serial.print(i);

    // センサーの初期化を試みる
    if (!bno_sensors[i].begin()) {
      Serial.println(" ... No BNO055 detected");
      sensor_initialized[i] = false;
    } else {
      Serial.println(" ... BNO055 Found!");
      bno_sensors[i].setExtCrystalUse(true); // 外部クリスタルを使用
      sensor_initialized[i] = true;
    }
  }
  delay(1000);

  // BLE初期化
  BLEDevice::init("XIAO_ESP32C6");
  BLEServer *pServer = BLEDevice::createServer();
  pServer->setCallbacks(new MyServerCallbacks());

  BLEService *pService = pServer->createService(SERVICE_UUID);

  // グローバル変数 pCharacteristic に代入
  pCharacteristic = pService->createCharacteristic(
                      CHARACTERISTIC_UUID,
                      BLECharacteristic::PROPERTY_READ |
                      BLECharacteristic::PROPERTY_WRITE |
                      BLECharacteristic::PROPERTY_NOTIFY
                    );

  pCharacteristic->setValue("Hello World");
  pService->start();
  // BLEAdvertising *pAdvertising = pServer->getAdvertising();  // this still is working for backward compatibility
  BLEAdvertising *pAdvertising = BLEDevice::getAdvertising();
  pAdvertising->addServiceUUID(SERVICE_UUID);
  pAdvertising->setScanResponse(true);
  pAdvertising->setMinPreferred(0x06);  // functions that help with iPhone connections issue
  pAdvertising->setMinPreferred(0x12);
  BLEDevice::startAdvertising();
  Serial.println("Setup Complete.");
}

void loop() {
  if (deviceConnected)
  {
    for (uint8_t i = 0; i < NUM_SENSORS; i++) 
    {
      if (sensor_initialized[i])
      {
        tcaselect(i); // 読み取りたいセンサーのポートを選択
        imu::Quaternion quat = bno_sensors[i].getQuat(); // クォータニオンデータを取得
        // データの作成
        String data = String(i) + ","
                      + String(quat.w(), 3) + ","
                      + String(quat.x(), 3) + ","
                      + String(quat.y(), 3) + ","
                      + String(quat.z(), 3);
        pCharacteristic->setValue(data.c_str());
        pCharacteristic->notify();
        Serial.println(data);
      }
      delay(BNO055_SAMPLERATE_DELAY_MS);
    }
  }
  delay(BNO055_SAMPLERATE_DELAY_MS);
}

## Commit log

2026-04-30 edit name
    [9jikuwithR-B_Cu.gbr, 9jikuwithR-B_Mask.gbr, 9jikuwithR-B_Paste.gbr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]
2026-05-08 edit posemagic scene powerup commnd
